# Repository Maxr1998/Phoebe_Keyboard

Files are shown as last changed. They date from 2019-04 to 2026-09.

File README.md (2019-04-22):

# Phoebe Keyboard

CAD files for case, plate and PCB of my Phoebe Mechanical Keyboard.

## License


All files in the repository are licensed under a [Creative Commons Attribution-ShareAlike 4.0 International License](http://creativecommons.org/licenses/by-sa/4.0/).

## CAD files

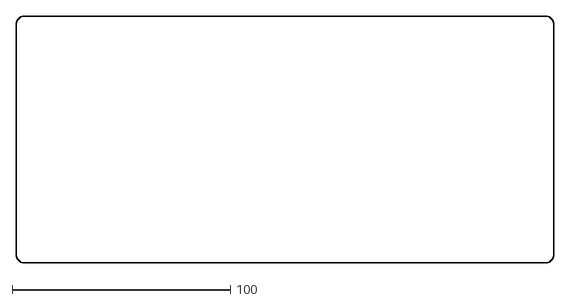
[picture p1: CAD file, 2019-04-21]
Bottom.dxf
246.6 x 113.3

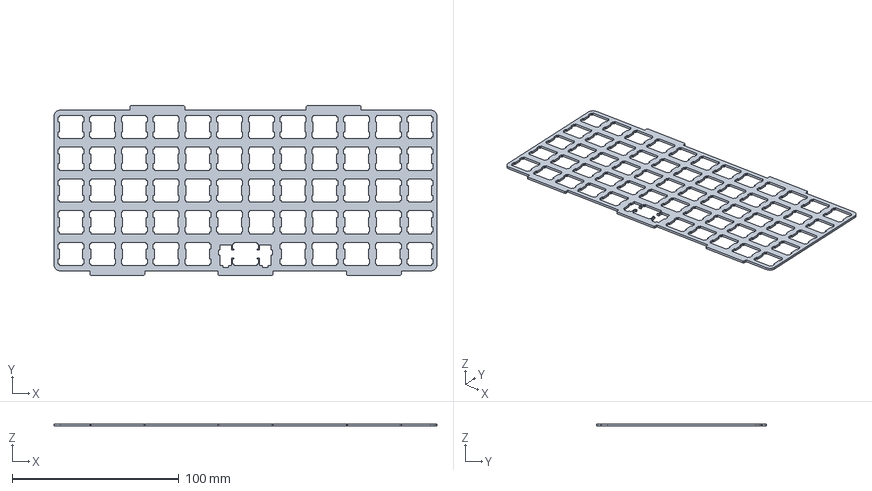
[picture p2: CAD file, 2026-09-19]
case_v2/plate.step
229.9 x 101.9 x 1.50 mm

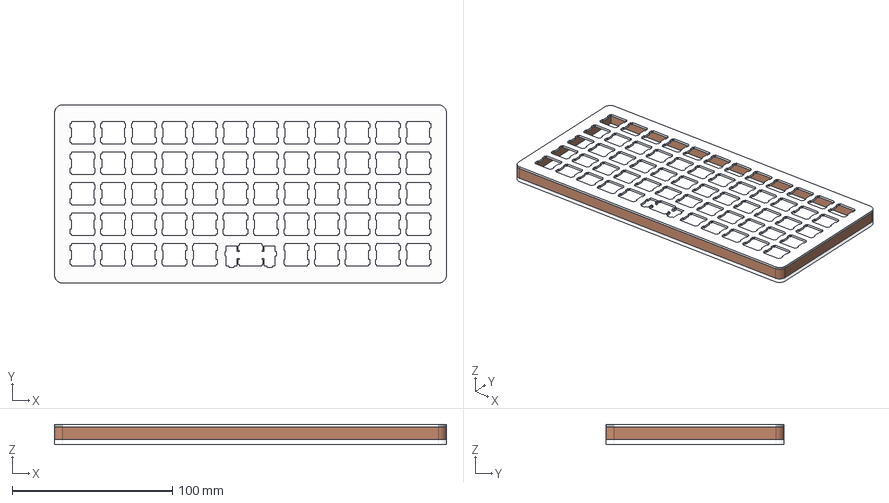
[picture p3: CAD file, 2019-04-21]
Case.fcstd
244.7 x 111.3 x 12.5 mm
Mid
Bottom
Plate

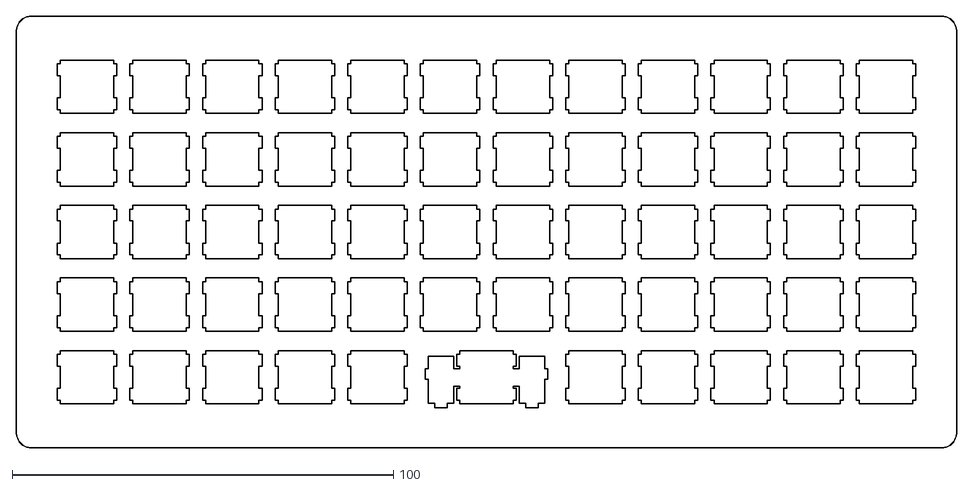
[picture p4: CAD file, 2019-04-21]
Plate_final.dxf
246.6 x 113.3

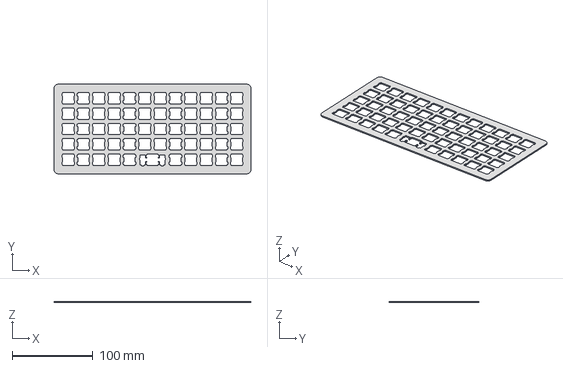
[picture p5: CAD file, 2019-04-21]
Plate.fcstd
244.6 x 111.3 x 1.50 mm

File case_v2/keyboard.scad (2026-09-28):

use <case_tub.scad>;
use <case_top_cover.scad>;

include <spec.scad>;
include <plate.scad>;
include <pcb.scad>;
include <keys.scad>;

preview_assembly = false;

color("white") {
  render()
    case_tub();
}

color("yellow") {
  render()
    case_top_cover();
}

if (preview_assembly) {
  translate([assembly_x, assembly_y, assembly_z]) {
    translate([0, 0, pcb_bot_z]) pcb();
    translate([0, 0, plate_bot_z]) plate();
    translate([0, 0, pcb_top_z]) keys();
  }
}

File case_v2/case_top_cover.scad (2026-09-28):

include <spec.scad>;
use <rounded_rect.scad>;

module case_top_cover() {
  color("yellow") {
    difference() {
      case_top_cover_outer();

      // Bottom tub
      bottom_tub_cutout();
      // Frame insides
      translate([case_top_wall_thickness, case_top_wall_thickness, case_tub_height - eps]) {
        rounded_rect_prism(
          size = [case_top_inner_width, case_top_inner_depth, case_top_height + 2 * eps],
          r = case_top_inner_radius
        );
      }
      // Screw holes
      for (screw_x = [screw_length_inset, case_width - screw_length_inset]) {
        for (screw_y = [screw_depth_inset, case_depth - screw_depth_inset]) {
          translate([screw_x, screw_y, case_tub_height - eps]) {
            screw_tap_hole();
          }
        }
      }
    }
  }
}

module case_top_cover_outer() {
  hull() {
    r = case_corner_outer_radius;
    for (x = [r, case_width - r], y = [r, case_depth - r]) {
      translate([x, y, 0]) {
        cylinder(h = case_floor_chamfer, r1 = r - case_floor_chamfer, r2 = r);
        translate([0, 0, case_floor_chamfer])
          cylinder(h = case_height - case_floor_chamfer - case_top_chamfer, r = r);
        translate([0, 0, case_height - case_top_chamfer])
          cylinder(h = case_top_chamfer, r1 = r, r2 = r - case_top_chamfer);
      }
    }
  }
}

module bottom_tub_cutout() {
  translate([case_top_skirt_thickness, -eps, -eps]) {
    rotate([90, 0, 0]) {
      mirror([0, 0, 1]) {
        half_rounded_rect_prism(
          size = [case_width - 2 * case_top_skirt_thickness, case_tub_height + eps, case_depth + 2 * eps],
          r = case_seam_radius
        );
      }
    }
  }
}

module screw_tap_hole() {
  cylinder(h = screw_tap_hole_length + eps, r = screw_tap_drill_diameter / 2);
}

case_top_cover();

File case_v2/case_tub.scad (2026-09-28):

include <spec.scad>;
include <udb.scad>;
use <logo.scad>;
use <rounded_rect.scad>;

module case_tub() {
  color("white") {
    difference() {
      case_tub_outer();

      // Main cavity
      translate([case_wall_thickness, case_wall_thickness, case_floor_thickness]) {
        rounded_rect_prism([case_tub_inner_width, case_tub_inner_depth, case_tub_height], r = case_tub_inner_radius);
      }
      // Gasket pockets
      translate([assembly_x, 0, case_tub_height - pocket_height]) {
        translate([0, case_depth - assembly_y]) {
          for (i = top_tabs_center_x) {
            translate([i, 0]) {
              pocket();
            }
          }
        }
        translate([0, assembly_y]) {
          for (i = bottom_tabs_center_x) {
            translate([i, 0]) {
              pocket();
            }
          }
        }
      }
      // Reset button
      reset_button_x = assembly_x + pcb_reset_button_center[0];
      reset_button_y = assembly_y + pcb_reset_button_center[1];
      reset_button_z = assembly_z + pcb_bot_z;
      translate([reset_button_x, reset_button_y, reset_button_z]) {
        reset_button_pocket();
      }
      // UDB + USB port
      translate([case_width / 2, case_depth - udb_port_wall_thickness, case_floor_thickness]) {
        udb();
      }
      // Screw holes
      for (screw_x = [screw_length_inset, case_width - screw_length_inset]) {
        for (screw_y = [screw_depth_inset, case_depth - screw_depth_inset]) {
          translate([screw_x, screw_y, -eps]) {
            screw_hole();
          }
        }
      }
      // Feet
      for (foot_x = [foot_length_inset, case_width - foot_length_inset - foot_pocket_width]) {
        for (foot_y = [foot_depth_inset, case_depth - foot_depth_inset - foot_pocket_depth]) {
          translate([foot_x, foot_y, -eps]) {
            # foot_pocket();
          }
        }
      }
      // Weight cavity
      weight_pocket_x = case_wall_thickness + weight_x;
      weight_pocket_y = case_wall_thickness + weight_y;
      weight_pocket_z = case_floor_thickness - weight_recess_depth;
      translate([weight_pocket_x, weight_pocket_y, weight_pocket_z]) {
        cube([weight_pocket_width, weight_pocket_depth, weight_recess_depth + eps]);
      }

      // Details
      detail_x = assembly_x + (pcb_edge_to_switch_distance - xda_keycap_width / 2);
      detail_gap = detail_x - case_tub_side_offset;

      // Logo
      logo_x = case_width - detail_x;
      logo_z = detail_face_bot_z + (detail_face_height - logo_height) / 2;
      translate([logo_x, case_depth + eps, logo_z]) {
        rotate([90, 0, 0]) {
          mirror([1, 0, 0]) {
            # linear_extrude(height = detail_engraving_depth + eps) {
              logo(height = logo_height, ascent = logo_ascent);
            }
          }
        }
      }
      // Face grooves
      groove_band_z = detail_face_bot_z + groove_band_margin;
      groove_length_front = case_width - 2 * detail_x;
      // Front
      for (i = [0 : groove_count - 1]) {
        groove_z = groove_band_z + i * groove_pitch;
        translate([detail_x, -eps, groove_z]) {
          # groove(length = groove_length_front);
        }
      }
      // Back
      logo_width = logo_width(height = logo_height, ascent = logo_ascent);
      groove_length_back = (case_width - udb_usb_mouth_width) / 2 - detail_x - detail_gap;
      for (i = [0 : groove_count - 1]) {
        groove_z = groove_band_z + i * groove_pitch;
        translate([detail_x, case_depth + eps, groove_z]) {
          # groove(length = groove_length_back, front = false);
        }
        translate([(case_width + udb_usb_mouth_width) / 2 + detail_gap, case_depth + eps, groove_z]) {
          groove_logo_inset = i > 0 && i < groove_count - 1
            ? logo_width + groove_gap
            : 0;
          # groove(length = groove_length_back - groove_logo_inset, front = false);
        }
      }
    }
  }
}

/**
 * The case bottom tubs outer hull with chamfered edges at the front/back bottom.
 */
module case_tub_outer() {
  intersection() {
    translate([case_tub_side_offset, -eps, 0]) {
      rotate([90, 0, 0]) {
        mirror([0, 0, 1]) {
          half_rounded_rect_prism(
            size = [case_tub_width, case_tub_height, case_tub_depth + 2 * eps],
            r = case_seam_radius
          );
        }
      }
    }
    translate([case_tub_side_offset - eps, 0, 0]) {
      rotate([90, 0, 90]) {
        linear_extrude(height = case_tub_width + 2 * eps) {
          // Bottom tub profile the from side with chamfer
          polygon([
              [case_floor_chamfer, 0],
              [case_tub_depth - case_floor_chamfer, 0],
              [case_tub_depth, case_floor_chamfer],
              [case_tub_depth, case_tub_height],
              [0, case_tub_height],
              [0, case_floor_chamfer]
            ]);
        }
      }
    }
  }
}

/**
 * Cutout for a plate-mount gasket pocket, centered on the tab position.
 *
 * Extends pocket_depth to BOTH sides of the wall's inner face, so the same module serves the front and back walls.
 * The half that reaches into the cavity cuts empty space and is harmless.
 */
module pocket() {
  translate([-pocket_width / 2, -pocket_depth]) {
    rounded_rect_prism([pocket_width, pocket_depth * 2, pocket_height + eps], r = pocket_radius);
  }
}

module screw_hole() {
  union() {
    cylinder(h = screw_counterbore_depth + eps, r = screw_counterbore_diameter / 2);
    cylinder(h = screw_counterbore_depth + eps + screw_length, r = screw_hole_diameter / 2);
  }
}

module foot_pocket() {
  rounded_rect_prism([foot_pocket_width, foot_pocket_depth, foot_pocket_height + eps], r = foot_pocket_radius);
}

module reset_button_pocket() {
  union() {
    translate([-reset_button_hole_width / 2, -reset_button_hole_width / 2, -reset_button_clearance_height]) {
      // No eps as it's positioned from pcb_bot_z
      rounded_rect_prism(
        size = [reset_button_hole_width, reset_button_hole_width, reset_button_clearance_height],
        r = reset_button_corner_radius
      );
    }
    translate([0, 0, -reset_button_hole_height]) {
      cylinder(h = reset_button_hole_height, r = reset_button_hole_radius);
    }
  }
}

module groove(length, front = true) {
  mirror([0, front ? 1 : 0, 0]) {
    rotate([90, 0, 0]) {
      rounded_rect_prism([length, detail_stroke_width, detail_engraving_depth + eps], r = detail_stroke_width / 2);
    }
  }
}

// Unused, but potentially useful for later
function face_edge_inset(z) = let(
  fillet_start_z = detail_face_top_z - case_seam_radius,
  rise = min(max(0, z - fillet_start_z), case_seam_radius)
) case_seam_radius - sqrt(case_seam_radius^2 - rise^2);

case_tub();

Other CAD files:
case_v2/keys.scad
Case.dxf
case_v2/logo.scad
case_v2/pcb.scad
case_v2/plate.dxf
case_v2/plate.scad
case_v2/rounded_rect.scad
case_v2/spec.scad
case_v2/udb.scad

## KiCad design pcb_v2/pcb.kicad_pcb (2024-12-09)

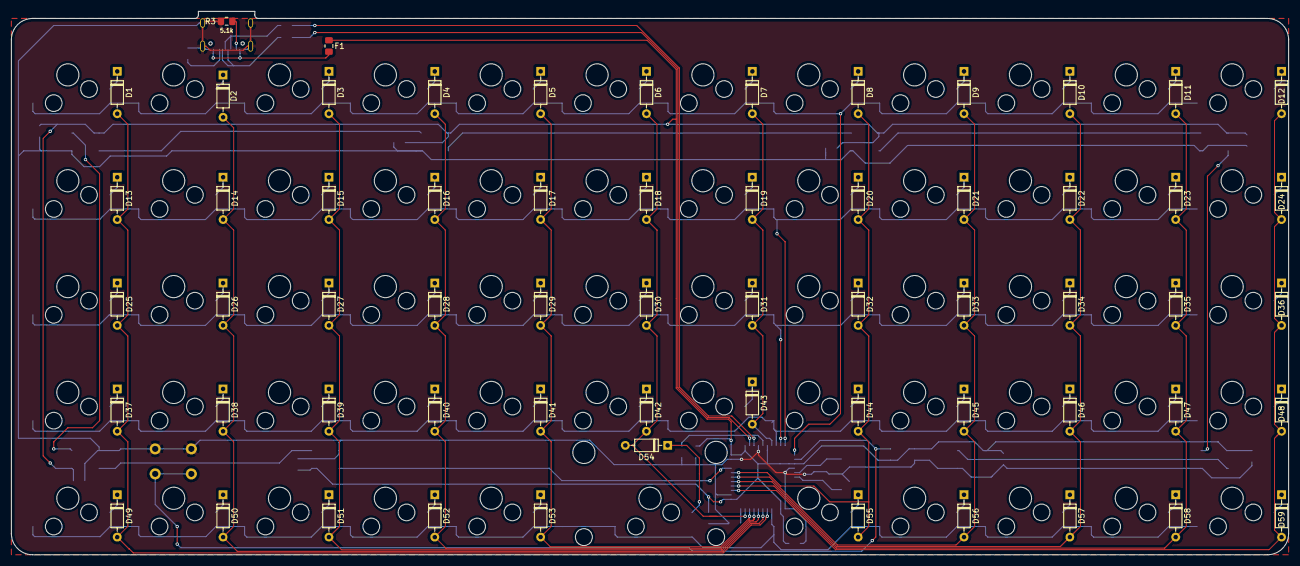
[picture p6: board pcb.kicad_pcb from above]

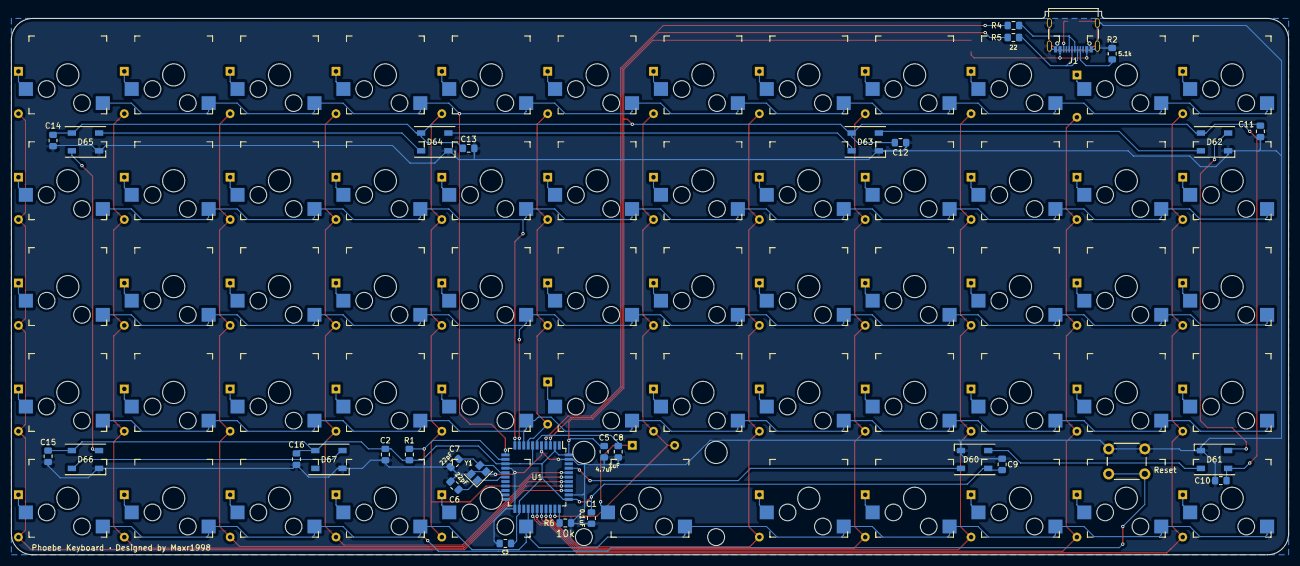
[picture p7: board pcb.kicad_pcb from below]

Board: 2 copper layers, 229.9 x 97.8 mm, 152 parts (32 on the bottom side), 98 nets.

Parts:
C1, C2, C3: 0.1uF; C_0805_2012Metric_Pad1.15x1.40mm_HandSolder
C5: 4.7uF; C_0805_2012Metric_Pad1.15x1.40mm_HandSolder
C6, C7: 22pF; C_0805_2012Metric_Pad1.15x1.40mm_HandSolder
C8: 1uF; C_0805_2012Metric_Pad1.15x1.40mm_HandSolder
C9, C10, C11, C12, C13, C14, C15, C16: 100nF; C_0805_2012Metric_Pad1.15x1.40mm_HandSolder
D1, D2, D3, D4, D5, D6, D7, D8, D9, D10, D11, D12, D13, D14, D15, D16, D17, D18, D19, D20, D21, D22, D23, D24, D25, D26, D27, D28, D29, D30, D31, D32, D33, D34, D35, D36, D37, D38, D39, D40, D41, D42, D43, D44, D45, D46, D47, D48, D49, D50, D51, D52, D53, D54, D55, D56, D57, D58, D59: 1N4148; D_DO-35_SOD27_P7.62mm_Horizontal
D60, D61, D62, D63, D64, D65, D66, D67: WS2812B; LED_WS2812B_PLCC4_5.0x5.0mm_P3.2mm
F1: 500mA; Fuse_0805_2012Metric_Pad1.15x1.40mm_HandSolder
J1: USB_C_Receptacle_USB2.0; USB_C_Receptacle_Palconn_UTC16-G
R1, R6: 10k; R_0805_2012Metric_Pad1.15x1.40mm_HandSolder
R2, R3: 5.1k; R_0805_2012Metric_Pad1.15x1.40mm_HandSolder
R4, R5: 22; R_0805_2012Metric_Pad1.15x1.40mm_HandSolder
SW1: Reset; SW_PUSH_6mm
SW2, SW3, SW4, SW5, SW6, SW7, SW8, SW9, SW10, SW11, SW12, SW13, SW14, SW15, SW16, SW17, SW18, SW19, SW20, SW21, SW22, SW23, SW24, SW25, SW26, SW27, SW28, SW29, SW30, SW31, SW32, SW33, SW34, SW35, SW36, SW37, SW38, SW39, SW40, SW41, SW42, SW43, SW44, SW45, SW46, SW47, SW48, SW49, SW50, SW51, SW52, SW53, SW54, SW55, SW56, SW57, SW58, SW59, SW60: SW_Push; Kailh_socket_plate_mount
U1: ATmega32U4-AU; TQFP-44_10x10mm_P0.8mm
Y1: TSX3225; Crystal_SMD_SeikoEpson_TSX3225-4Pin_3.2x2.5mm

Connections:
/CH_EN: R6.2, U1.33
/RESET: R1.1, SW1.2, U1.13
/XTAL_N: C7.1, U1.16, Y1.3
/XTAL_P: C6.2, U1.17, Y1.1
GND: C1.2, C2.2, C3.2, C5.2, C6.1, C7.2, C8.2, C9.2, C10.2, C11.2, C12.2, C13.2, C14.2, C15.2, C16.2, D60.3, D61.3, D62.3, D63.3, D64.3, D65.3, D66.3, D67.3, J1.A1, J1.A12, J1.B1, J1.B12, J1.S1, R2.1, R3.1, R6.1, SW1.1, U1.5, U1.15, U1.23, U1.35, U1.43, Y1.2, Y1.4
unnamed: C8.1, U1.6
unnamed: D1.1, SW2.2
unnamed: D2.1, SW3.2
unnamed: D3.1, SW4.2
unnamed: D4.1, SW5.2
unnamed: D5.1, SW6.2
unnamed: D6.1, SW7.2
unnamed: D7.1, SW8.2
unnamed: D8.1, SW9.2
unnamed: D9.1, SW10.2
unnamed: D10.1, SW11.2
unnamed: D11.1, SW12.2
unnamed: D12.1, SW13.2
unnamed: D13.1, SW14.2
unnamed: D14.1, SW15.2
unnamed: D15.1, SW16.2
unnamed: D16.1, SW17.2
unnamed: D17.1, SW18.2
unnamed: D18.1, SW19.2
unnamed: D19.1, SW20.2
unnamed: D20.1, SW21.2
unnamed: D21.1, SW22.2
unnamed: D22.1, SW23.2
unnamed: D23.1, SW24.2
unnamed: D24.1, SW25.2
unnamed: D25.1, SW26.2
unnamed: D26.1, SW27.2
unnamed: D27.1, SW28.2
unnamed: D28.1, SW29.2
unnamed: D29.1, SW30.2
unnamed: D30.1, SW31.2
unnamed: D31.1, SW32.2
unnamed: D32.1, SW33.2
unnamed: D33.1, SW34.2
unnamed: D34.1, SW35.2
unnamed: D35.1, SW36.2
unnamed: D36.1, SW37.2
unnamed: D37.1, SW38.2
unnamed: D38.1, SW39.2
unnamed: D39.1, SW40.2
unnamed: D40.1, SW41.2
unnamed: D41.1, SW42.2
unnamed: D42.1, SW43.2
unnamed: D43.1, SW44.2
unnamed: D44.1, SW45.2
unnamed: D45.1, SW46.2
unnamed: D46.1, SW47.2
unnamed: D47.1, SW48.2
unnamed: D48.1, SW49.2
unnamed: D49.1, SW50.2
unnamed: D50.1, SW51.2
unnamed: D51.1, SW52.2
unnamed: D52.1, SW53.2
unnamed: D53.1, SW54.2
unnamed: D54.1, SW55.2
unnamed: D55.1, SW56.2
unnamed: D56.1, SW57.2
unnamed: D57.1, SW58.2
unnamed: D58.1, SW59.2
unnamed: D59.1, SW60.2
unnamed: D60.2, D61.4
unnamed: D61.2, D62.4
unnamed: D62.2, D63.4
unnamed: D63.2, D64.4
unnamed: D64.2, D65.4
unnamed: D65.2, D66.4
unnamed: D66.2, D67.4
unnamed: J1.A5, R2.2
unnamed: J1.A6, J1.B6, R4.2
unnamed: J1.A7, J1.B7, R5.2
unnamed: J1.B5, R3.2
unnamed: R4.1, U1.4
unnamed: R5.1, U1.3
VBUS: F1.2, J1.A4, J1.A9, J1.B4, J1.B9
VCC: C1.1, C2.1, C3.1, C5.1, C9.1, C10.1, C11.1, C12.1, C13.1, C14.1, C15.1, C16.1, D60.1, D61.1, D62.1, D63.1, D64.1, D65.1, D66.1, D67.1, F1.1, R1.2, U1.2, U1.7, U1.14, U1.24, U1.34, U1.44
col0: D1.2, D13.2, D25.2, D37.2, D49.2, U1.27
col1: D2.2, D14.2, D26.2, D38.2, D50.2, U1.28
col2: D3.2, D15.2, D27.2, D39.2, D51.2, U1.29
col3: D4.2, D16.2, D28.2, D40.2, D52.2, U1.30
col4: D5.2, D17.2, D29.2, D41.2, D53.2, U1.31
col5: D6.2, D18.2, D30.2, D42.2, D54.2, U1.32
col6: D7.2, D19.2, D31.2, D43.2, U1.8
col7: D8.2, D20.2, D32.2, D44.2, D55.2, U1.40
col8: D9.2, D21.2, D33.2, D45.2, D56.2, U1.39
col9: D10.2, D22.2, D34.2, D46.2, D57.2, U1.38
col10: D11.2, D23.2, D35.2, D47.2, D58.2, U1.37
col11: D12.2, D24.2, D36.2, D48.2, D59.2, U1.36
led0: D60.4, U1.41
row0: SW2.1, SW3.1, SW4.1, SW5.1, SW6.1, SW7.1, SW8.1, SW9.1, SW10.1, SW11.1, SW12.1, SW13.1, U1.12
row1: SW14.1, SW15.1, SW16.1, SW17.1, SW18.1, SW19.1, SW20.1, SW21.1, SW22.1, SW23.1, SW24.1, SW25.1, U1.11
row2: SW26.1, SW27.1, SW28.1, SW29.1, SW30.1, SW31.1, SW32.1, SW33.1, SW34.1, SW35.1, SW36.1, SW37.1, U1.10
row3: SW38.1, SW39.1, SW40.1, SW41.1, SW42.1, SW43.1, SW44.1, SW45.1, SW46.1, SW47.1, SW48.1, SW49.1, U1.9
row4: SW50.1, SW51.1, SW52.1, SW53.1, SW54.1, SW55.1, SW56.1, SW57.1, SW58.1, SW59.1, SW60.1, U1.26

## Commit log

2019-04-21 Add bottom plate
    [Bottom.dxf]
2019-04-22 Add PCB design
    [pcb.kicad_pcb, pcb.sch]
2019-04-22 Add a fuse between VBUS and VCC
    [pcb.kicad_pcb, pcb.sch]
2019-04-22 Add decoupling capacitors for LEDs
    [pcb.kicad_pcb, pcb.sch]
2019-04-22 Export settings
    [pcb.kicad_pcb]
2019-04-22 Add Gerber files
    [pcb-B_Cu.gbr, pcb-B_Mask.gbr, pcb-B_Paste.gbr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]
2019-04-22 Add distance measurement for spacebar switch
    [pcb.kicad_pcb]
2019-04-23 Add name and author to PCB
    [pcb-B_Cu.gbr, pcb-B_Mask.gbr, pcb-B_Paste.gbr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]
2019-05-02 Add infill, reroute col11
    [pcb.kicad_pcb]
2019-05-02 Update gerber files
    [pcb-B_Cu.gbr, pcb-B_Mask.gbr, pcb-B_Paste.gbr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]
2019-05-02 Remove switch labels
    [pcb-B_Cu.gbr, pcb-B_Mask.gbr, pcb-B_Paste.gbr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]
2019-05-24 Add mid-layer dxf
    [Case.dxf]
2019-07-12 Add some dimension markers
    [pcb.kicad_pcb]
2019-07-12 Update case scheme
    Add cutout for USB port
    [Case.dxf]
2019-12-04 Rework PCB design
    New USB plug, better placement of capacitors, different footprint for crystal
    [pcb.kicad_pcb, pcb.sch]
2024-12-09 Upgrade to latest KiCAD and tweak measurements
    [pcb.kicad_pcb]
2026-09-19 Plate design for case v2
    [plate.dxf, plate.step]
2026-09-28 Case v2 design
    [case_top_cover.scad, case_tub.scad, keyboard.scad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]
